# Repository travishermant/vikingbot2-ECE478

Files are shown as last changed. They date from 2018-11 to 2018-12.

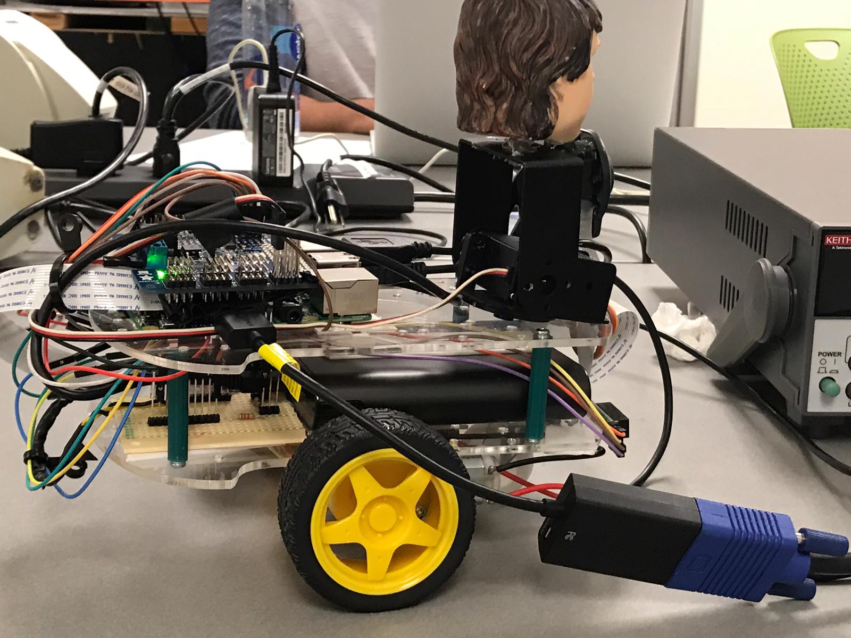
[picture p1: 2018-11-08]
Documentation/Pictures/RightView.jpeg

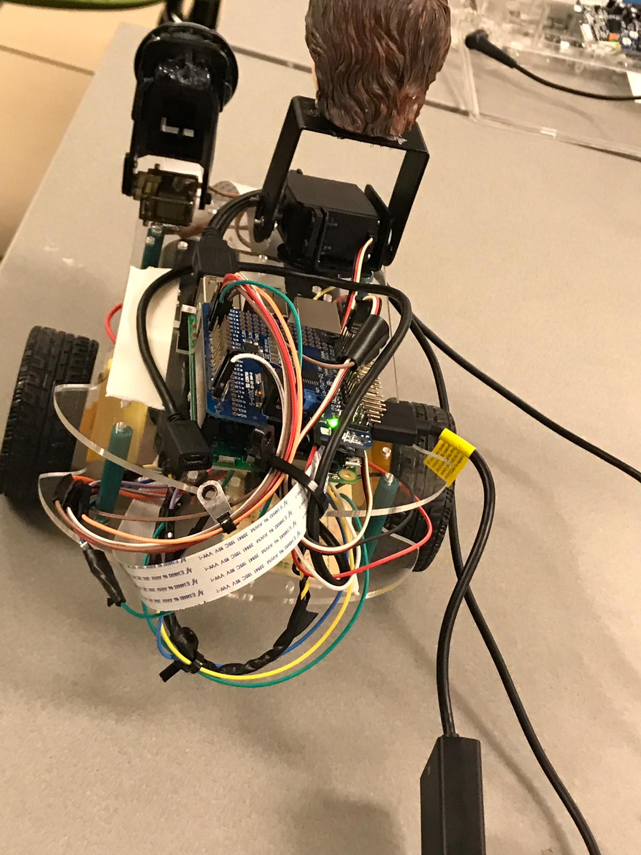
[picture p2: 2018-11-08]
Documentation/Pictures/RearView.jpeg

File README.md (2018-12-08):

# Fall 2018 - ECE478/578 - Intelligent Robotics 1
**Intelligent Robotics Lab**

**Portland State University**

# Members
- Travis Hermant (https://github.com/travishermant)
- Abdullah Barghouti (https://github.com/AbdullahBarghouti)
- Jagir Charla Laxmichand (https://github.com/gotu0000)
- Abdirahman Alasow (https://github.com/abdi-alasow)

# Project Name: Vikingbot

Vikingbot is a small motor-driven robot utilizing Python, ROS, Dialogflow, Amazon Polly, and OpenCV to perform different applications
  
# Project Goals

Facial Recognition
- Vikingbot rotates to align itself with faces it detects in front [done]

Gesture Recognition
- Vikingbot will nod its head when it sees a smile [done]

Color Tracking
- Vikingbot will rotate and follow an orange ball when it is detected [done]

IR Sensors
- Vikingbot will prevent itself from crashing by using IR sensors to detect distance from obstacles [done]

Speech to Text
- Using Dialogflow to check intents and respond with the correct actions [done]

Text to Speech
- Using Amazon Polly to convert lines of dialogue to MP3's so they can be played through speakers [done]

ROS Integration
- Previous components can now be used in conjunction with ROS rather than being used individually (No OpenCV yet) [done]

# Hardware and Software used

Software:
- OpenCV
- Python
- ROS
- Dialogflow
- Amazon Polly

Hardware: 
- Raspberry Pi 3B
- Raspberry Pi Camera
- L2938N H-Bridge
- Adafruit Servo Controller Hat
- Futaba S3003 Servo
- SDS02A Pololu IR Sensor
- 2x DC Motor Wheel Components

# Contributions
- Travis (3D Model, Servo Control, Github Organization, Dialogflow)
- Abdullah (Motor Control, Servo Control, Polly)
- Jagir (Gesture Recognition, Color Tracking, ROS)
- Abdi (Facial Recognition, Dialogflow)

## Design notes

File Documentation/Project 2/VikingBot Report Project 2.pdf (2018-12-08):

# Vikingbot

Travis Hermant
Abdullah Barghouti
Abdirahman Alasow
Jagir Laxmichand Charla

ECE 478-578 Intelligent Robotics I

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
4 Intro | 4 Overview | 4 Challenges | 7 Possible improvements | 7

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
8 Intro | 8 Overview Diagrams | 8 Coordinator | 10 Motor Motion | 10 Servo Motion | 10 Recorder | 10 Dialogflow | 10 Polly | 11 Talker | 11 Challenges | 11 Possible improvements | 11

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
2 Intro | 12 Overview | 12 Challenges | 12 Possible improvements | 13

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
4 Intro | 14 Design | 15 Challenges | 15 Possible improvements | 16

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
# Summary

The Vikingbot contains two DC motors for the wheels driven by an L293E H-Bridge making it capable of operating both wheels forward and backward in conjunction, or allows each to operate in separate directions to allow it to turn. Central processing is handled by a
Raspberry Pi 3 B with an attached Adafruit Servo Hat for PWM control of the attached servo. Coding is done with Python; an attached Pi Camera is used in conjunction with OpenCV to handle applications such as color tracking with a ball, face tracking to steer the car, and smile recognition to make the servos respond to gestures. The Vikingbot utilizes ROS to facilitate using Dialogflow to interpret commands, Amazon Polly to communicate with users, and to drive the motors and servos.

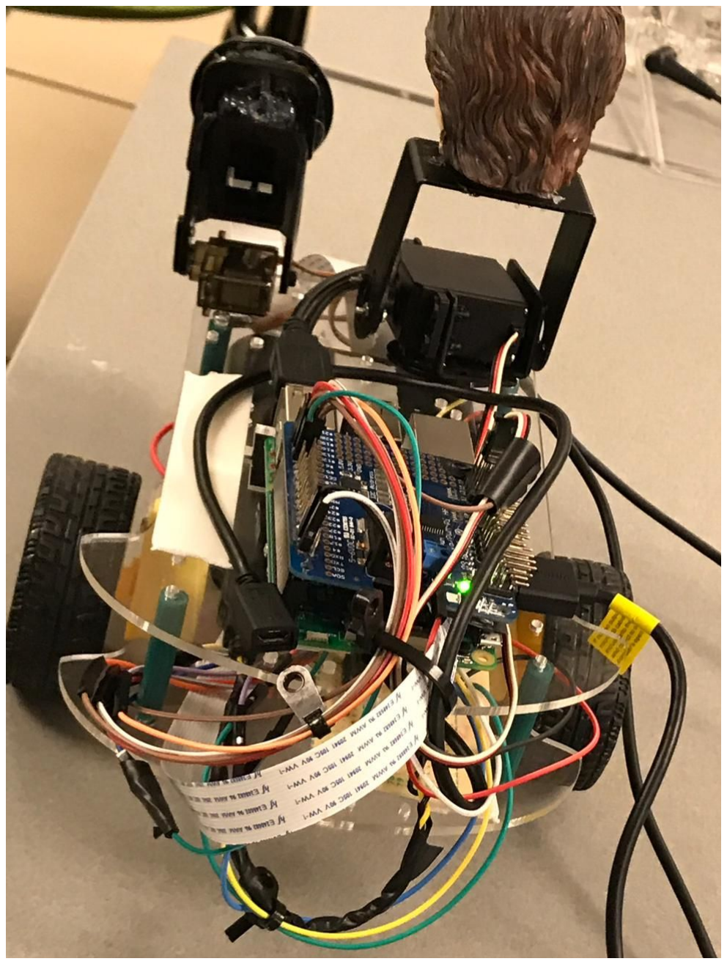
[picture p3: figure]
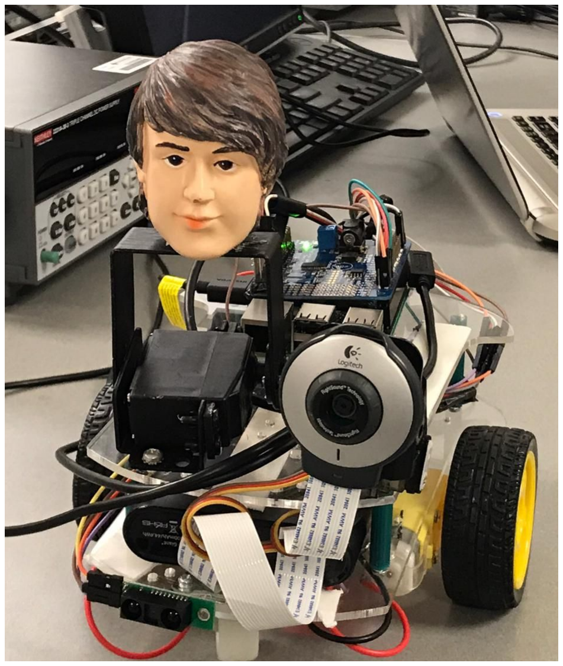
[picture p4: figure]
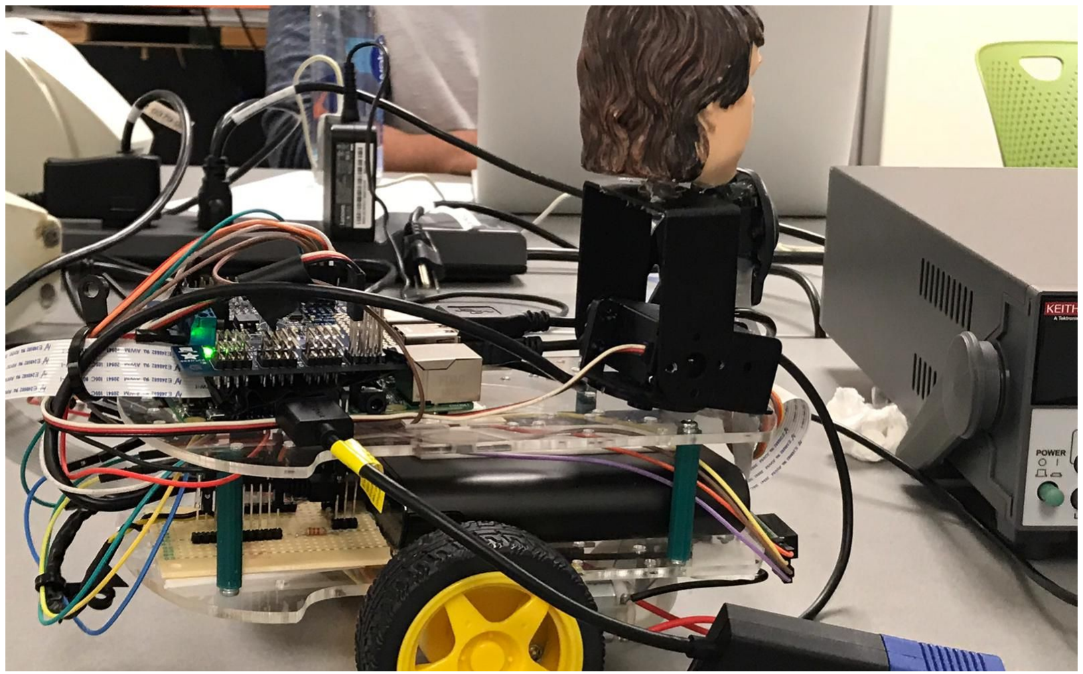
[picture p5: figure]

# Software Design

## Intro

We have 4 different independent applications for the demo:
- Ball Tracking Bot
- Face Tracking Bot
- Remote Controlled Bot
- Smile Detector Bot
Which can be broadly divided into two parts like Vision and Motion.

We have used OpenCV with python for the Vision and we have used RPI’s GPIO module for the motion.

## Overview

For Remote Controlled Bot we have made two applications talking over TCP socket. The one which actually executes the motion is TCP Server , whose task is listen to the command and execute it according to the request generated from TCP Client.

TCP Client takes data from a user in the form of letters ‘w’, ’a’, ‘s’, ‘d’ and ‘b’:
‘w’ for forward
‘a’ for left
‘s’ for stop
‘d’ for right
And ‘b’ for backward

Server also monitors IR sensor to check for the obstacle in front. It stops the motion in case of detection of obstacle.

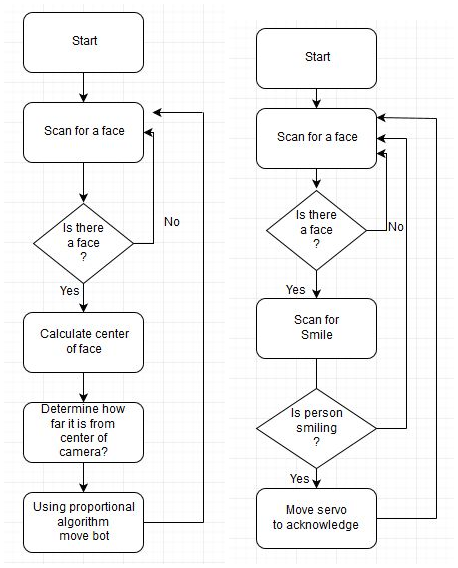
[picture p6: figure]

For smile detecting bot we have used Haar cascade classifier to detect a face in an image. After getting a face we are looking for smile in the region of interest using Haar cascade smile classifier. Depending on detection of smile we are moving the servo to make it look like a greeting gesture.
For face tracking bot we have used Haar cascade classifier to detect a face in an image. For tracking we are calculating the center of the face and determining how far it is from the center of camera. Depending on which we are rotating the bot till center of the face gets align to the center of the camera.

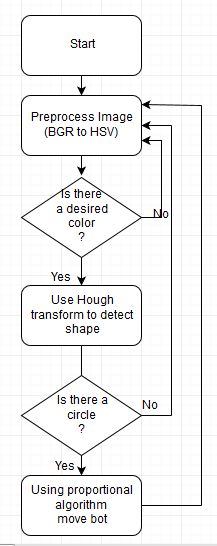
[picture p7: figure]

For ball tracking bot we have converted an image to HSV. HSV is good for color segmentation purpose. We are using hough transform to determine circles in an image. For tracking we are calculating the center of the circle and determining how far it is from the center of camera. Depending on which we are rotating the bot till center of the ball gets align to the center of the camera. After that we are comparing the area of the circle to determine how far the ball is from camera, and accordingly we are moving the bot forward if area is too small.

## Challenges

Face detection and ball detection are prone to misbehave in case of poor lighting condition. Apart from that due to various morphological operations involved in pre processing frame rate reduces.

## Possible improvements

Implementation of robust and fast methods for detection of face and ball, and integration of multiple Vision algorithms to make bot more interactive.

# ROS Design

## Intro

We have 7 different ROS nodes working in conjunction.
- Coordinator
- Motor Motion
- Servo Motion
- Recorder
- Dialogflow
- Polly
- Talker
These nodes can be used in conjunction for speech to text, text to speech, and motion commands. Currently OpenCV and Color/Facial recognition are not implemented for use in ROS.

## Overview Diagrams

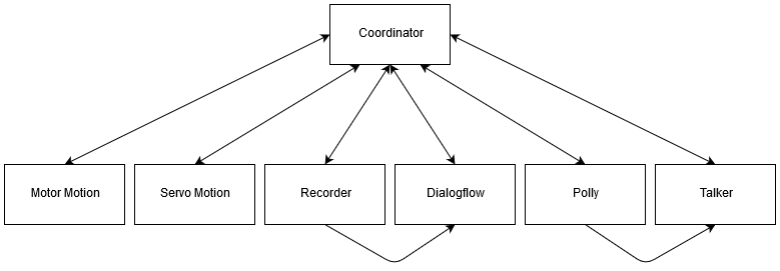
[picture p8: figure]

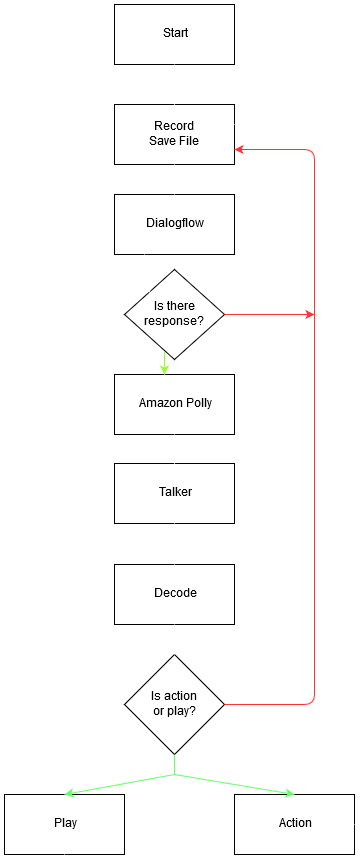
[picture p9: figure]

## Coordinator

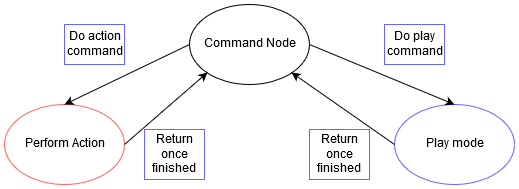
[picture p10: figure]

The coordinator node is the “brain” of the robot, deciding what should be done and sending commands to all of the nodes.

## Motor Motion

The motor motion node is a conversion of our previous driver so that they’re compatible with ROS. It is capable of moving forward, turning left and right, and going backwards.

## Servo Motion

The servo motion node is also a conversion of our previous driver for controlling the servo that the bobble head sits on. Since there is only one servo, it is only capable of one degree of freedom and can move in a 180 degree arc. Currently its usage is limited to nodding as a form of expression. In the future it will be adapted to accompany additional servos for the arms.

## Recorder

The recorder node is where the microphone will catch audio in 5 second loops and convert them into WAV files. The audio isn’t parsed here though, and will instead need to be sent out to the Dialogflow node

## Dialogflow

The Dialogflow node will send the WAV files it receives from the Recorder node to the Google API servers, where it will be analyzed to return the intent so that the proper actions can be taken. Actions Dialogflow can detect are: entering ‘theater’ mode, turning ‘left’, turning ‘right’, going ‘forward’, and going ‘backward’.

## Polly

The Amazon Polly node is used to convert text to speech. Lines of the play are sent in a string to the AWS servers, where the string is then converted to an MP3 files. Polly is configured to speak in a Male British accent, to coincide with our play script following Alan Turing.

## Talker

The Talker node is used to drive the speakers with MP3s that are generated by Amazon Polly. The talker node also takes in the spoken speech and decodes it to identify what mode/ action the robot should enter.

## Challenges

ROS is difficult to set up and having the capability of running nodes on different computers is nice, but also complicated. It is difficult to use Amazon Polly and Dialogflow because they both require internet and establishing a connection to the internet in conjunction with multiple robots/computers is also a complicated task.

## Possible improvements

Currently, the Vikingbot is running solo and does not have any communication set up between it and another robot. A method of communication between the raspberry pi, a parent computer, and another robot is vital for further development.
Pulse Width Modulation should be added to the motor for the wheels, so that we can vary the speed at which the robot moves around. PWM would greatly increase our ability to emote and give greater control over what we want it to do.
We still have our temporary design in use due to complications with the 3D printers, so we’re limited in what we can do to increase functionality through hardware. Eventually when we have the new design, we can add new components such as an extra battery to separate the power draw from the servos, which would allow us to add more servos.

# Hardware Design

## Intro

During our initial stages of designing and assembling the robot’s hardware, we figured it would be useful to list the parts we will make use of in our robot design. From our group discussions, we concluded that we would incorporate the DC motors that came with the robot base, raspberry pi 3b, raspberry pi hat, servo motors, portable battery pack, and an IR infrared obstacle avoidance sensor. We also used a voltage divider to step down the voltage from the power supply from 5v to 3.3v so that it can be wired to the raspberry pi pins safely.
We used the raspberry pi hat as a safety precaution to ensure that the servo motors we attach to the main board don’t draw too much power and damage our raspberry pi. The Hardware Attached on Top (HAT) also allows us to connect up to 16 servo motors and has a 5-volt input to ease the power draw on our main board.

## Overview

To use the raspberry pi pins, we had to use a voltage divider with a 1k ohm and 2k ohm resistors so that the power input on the pins is dropped from 5v to the rated 3.3 volts. To connect the servo motors we used the hardware attached on the top chip to protect the main board from any access power draw. This chip allows for protection and adds the capability to add up to 16 servos and another power input to suffice the needed current and voltage to power all the added components connected to it.
Our current design allows for the servo motor with the bobblehead to move in a single direction (upwards and downwards), our design, however, allows for up to 2 motors (right and left movement as well) but because of the power limitations, we had to omit the second servo.

## Challenges

Because of our limited power supply, we had issues connecting more than one servo to our robot. Connecting the servos, raspberry pi, DC motors, and the camera drew just enough power that adding another servo motor caused the raspberry pi to shut off.
Setting up google dialog flow was tedious at first but the video uploaded by Melih Erdogan made things more manageable.
Due to the limited bandwidth, the connection between the raspberry pi and host computer was lagging and causing lots of delays. To overcome this challenge, we were forced to use a wired connection

## Possible improvements

The power supply that we used was not powerful enough to support all the components we had connected to it. A future improvement would be to find a better alternative to supply the needed power to all our components while still keeping the robot relatively light and mobile.

# Enclosure Design

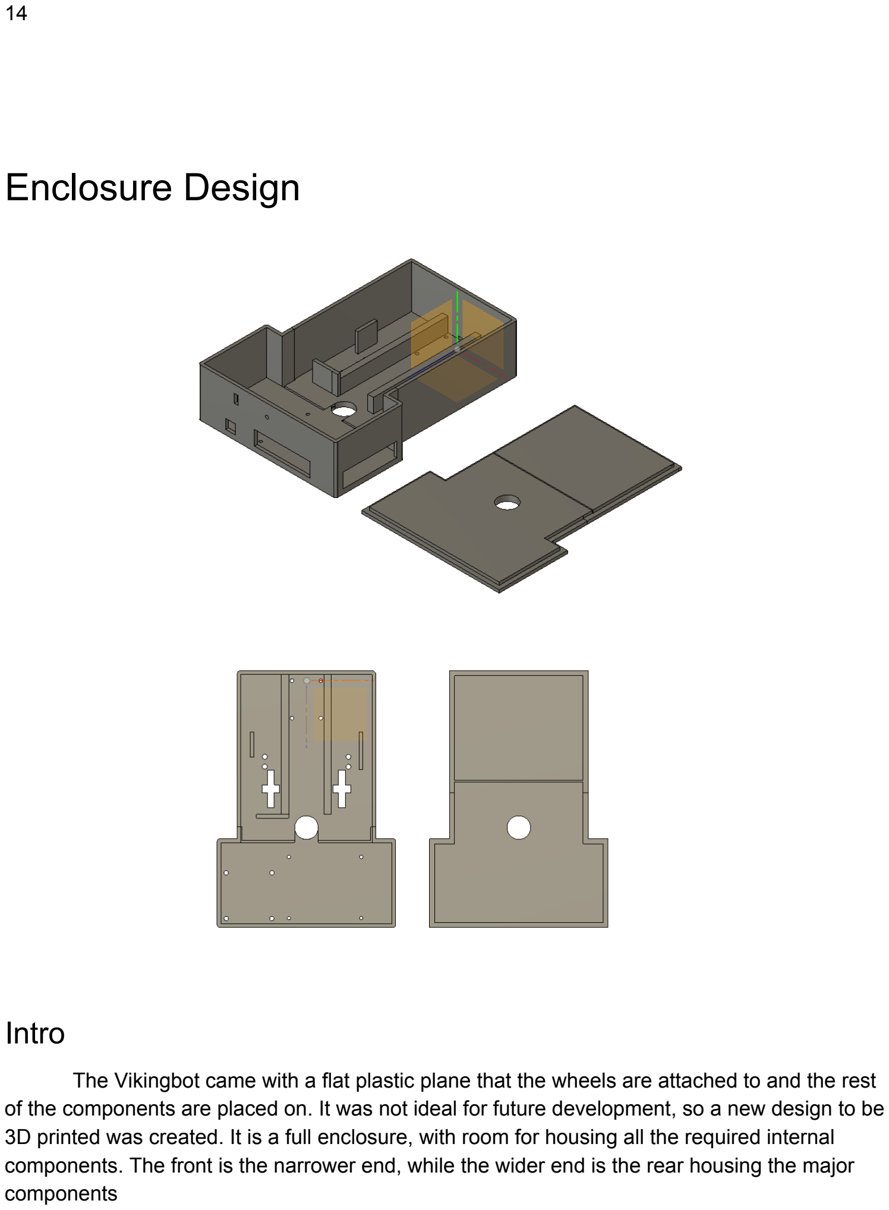
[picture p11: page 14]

## Intro

The Vikingbot came with a flat plastic plane that the wheels are attached to and the rest of the components are placed on. It was not ideal for future development, so a new design to be 3D printed was created. It is a full enclosure, with room for housing all the required internal components. The front is the narrower end, while the wider end is the rear housing the major components

## Design

The enclosure is roughly 50mm tall, allowing ample room for components to rest inside without cramping wires or worrying about heating issues. The battery is easily the largest component in the Vikingbot, and is placed on small stands at the front of the enclosure to keep the center of gravity on the wheels and help any potential stability issues. The input and output of the battery will be facing inwards, which then makes charging difficult. To circumvent that issue we connected a micro USB extension cable and added a cutout in the back of the model for charging purposes. In the future there will be encoder wheels located in the cross shaped cutouts; the battery was placed on stands a few millimeters more than the encoder wheels should require.
The Raspberry Pi will be located in the bottom right corner of the enclosure and has four corresponding screw holes for security, with cutouts in the enclosure corresponding to the Pi’s USB and HDMI ports so they can be accessed from the outside. Since the Pi has the Servo Hat installed on it, it will be considerably taller than without, but the large amount of clearance shouldn’t make that an issue.
The H-Bridge will be located in the bottom left corner of the enclosure, with its own corresponding four screw holes. There is a small amount of room in the rear compartment for relevant connections or solder boards to rest, although there is no specific security points for them.
The large hole in the center of the base and lid provides a place for wires to safely route through. The hole for the base will have the H-Bridge wires to connect to the bottom motors. The hole in the lid will have wires for the camera and servo to run through. There is a small, rectangular slit located in the front and back for the IR sensors to have safe places to run their connections through. The two sets of two holes directly next to the cross shaped cutouts are for the motor driven wheel screws, the four holes near the front are for the supporting wheel to attach to for balance

## Challenges

Due to the length of the enclosure (roughly 205mm) it would not be able to print with our current 3D printers. To circumvent this, we cut the base and lid into their own separate halves and have decided to either glue or drill through and screw together when finished printing. This raises concerns for stability issues, but with sufficient enough fastening should not pose an issue. One benefit however is that it adds slightly more modularity, as now modifications in the 3D model design would only have to be done in sections, rather than having to print the entire enclosure again.
There were unforeseen issues with 3D printers on campus, and we weren’t able to have the models printed in time for the demo and end of project 1. As a temporary solution we used the base of the other Vikingbot and added some spacers so some components could be sat on top. It is functional enough in its current state, but somewhat difficult to work with and not too pleasant to look at.

## Possible improvements

As it stands now, the lid is free of any mounting holes aside from the hole to route wires through. Once the location of servos and cameras is finalized they can be added to the 3D design. The mounting locations on the front and back for the IR sensors will most likely fail when it comes to 3D printing, so their locations may need to be modified or otherwise changed so that drilling a hole isn’t necessary.
Depending on any stability issues due to the base and lid being split in half, the 3D design may need to be changed to better allocate support and have added dedicated holes to screw both pieces together.
While mostly functional in application, the final design is a little on the boring side. The simple ‘T’ shape can be changed into interesting ways. We may also want to have a custom 3D printed head/body for the lid to fully integrate each aspect of the Vikingbot.

# Conclusion

This project incorporated all the movement and functionality that we had in the first project. For this project we used ROS to publish and subscribe to nodes, Google Dialogflow to create text from speech, and Amazon Polly to create speech from text. By the end of the project, the VikingBot supported motion, computer vision, speech to text, and text to speech.

# Resources

Github:
https://github.com/travishermant/vikingbot2-ECE478
Youtube:
https://www.youtube.com/channel/UClnZui7ccUFAsCJwCExTw2A

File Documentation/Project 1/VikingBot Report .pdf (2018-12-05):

# Vikingbot

Travis Hermant
Abdullah Barghouti
Abdirahman Alasow
Jagir Laxmichand Charla

ECE 478-578 Intelligent Robotics I

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
alle

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
sible im

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
8 Intro | 8 Design | 8 Challenges | 9 Possible improvements | 9

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
0 Intro | 10 Design | 11 Challenges | 11 Possible improvements | 12

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
# Summary

The Vikingbot contains two DC motors for the wheels driven by an L293E H-Bridge making it capable of operating both wheels forward and backward in conjunction, or allows each to operate in separate directions to allow it to turn. Central processing is handled by a
Raspberry Pi 3 B with an attached Adafruit Servo Hat for PWM control of the attached servos. Coding is done with Python; an attached Pi Camera is used in conjunction with OpenCV to handle applications such as color tracking with a ball, face tracking to steer the car, and smile recognition to make the servos respond to gestures.

# Software

# Intro

We have 4 different independent applications for the demo.
- Ball Tracking Bot
- Face Tracking Bot
- Remote Controlled Bot
- Smile Detector Bot
Which can be broadly divided into two parts like Vision and Motion.

We have used OpenCV with python for the Vision and we have used RPI’s GPIO module for the motion.

## Design

For Remote Controlled Bot we have made two applications talking over TCP socket. The one which actually executes the motion is TCP Server , whose task is listen to the command and execute it according to the request generated from TCP Client.

TCP Client takes data from a user in the form of letters ‘w’, ’a’, ‘s’, ‘d’ and ‘b’

‘w’ for forward
‘a’ for left
‘s’ for stop
‘d’ for right
And ‘b’ for backward

Server also monitors IR sensor to check for the obstacle in front. It stops the motion in case of detection of obstacle.

For face tracking bot we have used Haar cascade classifier to detect a face in an image. For tracking we are calculating the center of the face and determining how far it is from the center of camera. Depending on which we are rotating the bot till center of the face gets align to the center of the camera.

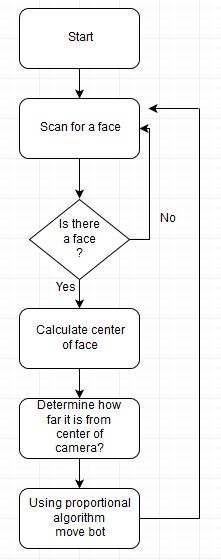
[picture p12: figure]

For smile detecting bot we have used Haar cascade classifier to detect a face in an image. After getting a face we are looking for smile in the region of interest using Haar cascade smile classifier. Depending on detection of smile we are moving the servo to make it look like a greeting gesture.

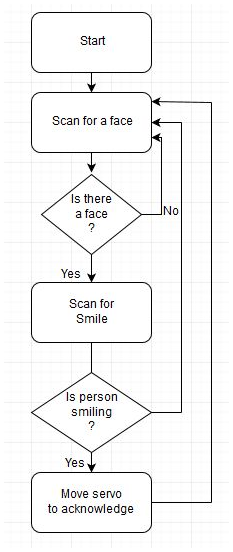
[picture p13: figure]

For ball tracking bot we have converted an image to HSV. HSV is good for color segmentation purpose. We are using hough transform to determine circles in an image. For tracking we are calculating the center of the circle and determining how far it is from the center of camera. Depending on which we are rotating the bot till center of the ball gets align to the center of the camera. After that we are comparing the area of the circle to determine how far the ball is from camera, and accordingly we are moving the bot forward if area is too small.


## Challenges

Face detection and ball detection are prone to misbehave in case of poor lighting condition. Apart from that due to various morphological operations involved in pre processing frame rate reduces.

## Possible improvements

Implementation of robust and fast methods for detection of face and ball. And Integration of multiple Vision algorithms to make bot more interactive.

# Hardware

## Intro

During our initial stages of designing and assembling the robot’s hardware, we figured it would be useful to list the parts we will make use of in our robot design. From our group discussions, we concluded that we would incorporate the DC motors that came with the robot base, raspberry pi 3b, raspberry pi hat, servo motors, portable battery pack, and an IR infrared obstacle avoidance sensor. We also used a voltage divider to step down the voltage from the power supply from 5v to 3.3v so that it can be wired to the raspberry pi pins safely.
We used the raspberry pi hat as a safety precaution to ensure that the servo motors we attach to the main board don’t draw too much power and damage our raspberry pi. The Hardware Attached on Top (HAT) also allows us to connect up to 16 servo motors and has a 5-volt input to ease the power draw on our

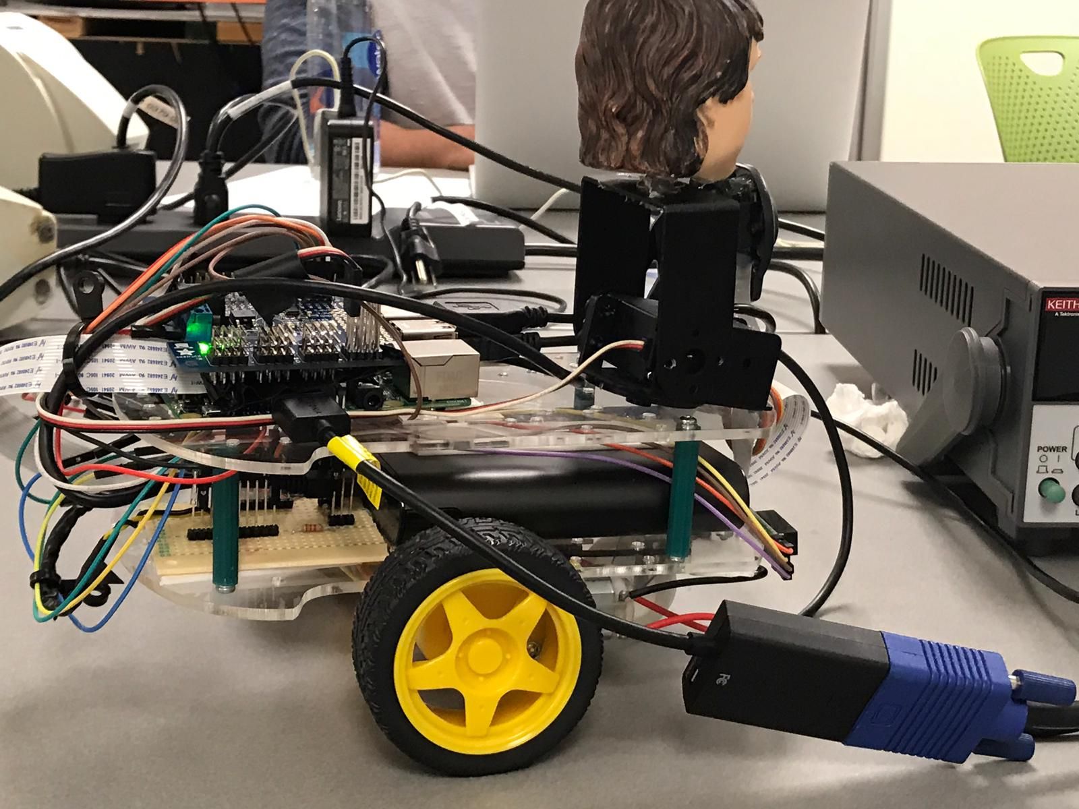
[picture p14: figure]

main board.

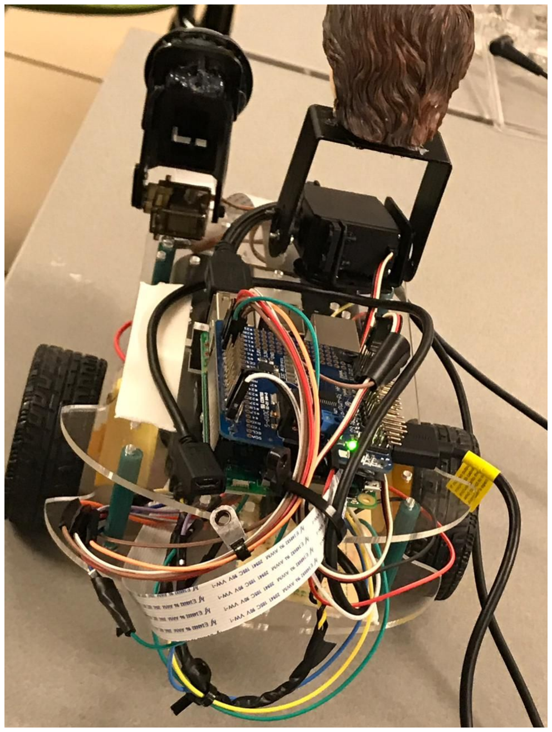
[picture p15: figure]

## Design

To use the raspberry pi pins, we had to use a voltage divider with a 1k ohm and 2k ohm resistors so that the power input on the pins is dropped from 5v to the rated 3.3 volts. To connect the servo motors we used the hardware attached on the top chip to protect the main board from any access power draw. This chip allows for protection and adds the capability to add up to 16 servos and another power input to suffice the needed current and voltage to power all the added components connected to it. Our current design allows for the servo motor with the bobblehead to move in a single direction (upwards and downwards), our design, however, allows for up to 2 motors (right and left movement as well) but because of the power limitations, we had to omit the second servo.

## Challenges

Because of our limited power supply, we had issues connecting more than one servo to our robot. Connecting the servos, raspberry pi, DC motors, and the camera drew just enough power that adding another servo motor caused the raspberry pi to shut off.

## Possible improvements

The power supply that we used was not powerful enough to support all the components we had connected to it. A future improvement would be to find a better alternative to supply the needed power to all our components while still keeping the robot relatively light and mobile.

# Enclosure Design

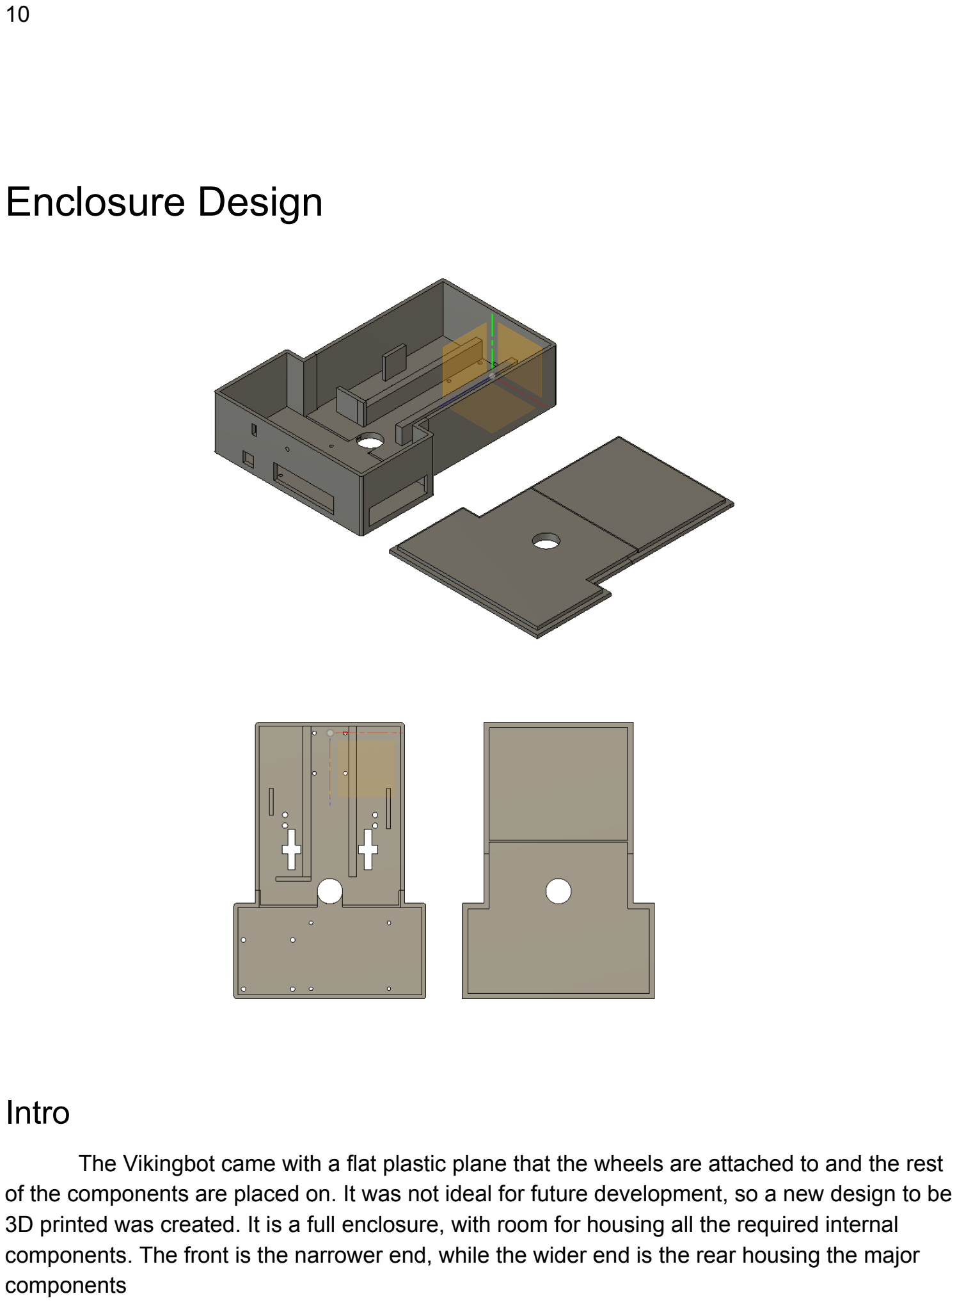
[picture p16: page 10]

## Intro

The Vikingbot came with a flat plastic plane that the wheels are attached to and the rest of the components are placed on. It was not ideal for future development, so a new design to be 3D printed was created. It is a full enclosure, with room for housing all the required internal components. The front is the narrower end, while the wider end is the rear housing the major components

## Design

The enclosure is roughly 50mm tall, allowing ample room for components to rest inside without cramping wires or worrying about heating issues. The battery is easily the largest component in the Vikingbot, and is placed on small stands at the front of the enclosure to keep the center of gravity on the wheels and help any potential stability issues. The input and output of the battery will be facing inwards, which then makes charging difficult. To circumvent that issue we connected a micro USB extension cable and added a cutout in the back of the model for charging purposes. In the future there will be encoder wheels located in the cross shaped cutouts; the battery was placed on stands a few millimeters more than the encoder wheels should require.
The Raspberry Pi will be located in the bottom right corner of the enclosure and has four corresponding screw holes for security, with cutouts in the enclosure corresponding to the Pi’s USB and HDMI ports so they can be accessed from the outside. Since the Pi has the Servo Hat installed on it, it will be considerably taller than without, but the large amount of clearance shouldn’t make that an issue.
The H-Bridge will be located in the bottom left corner of the enclosure, with its own corresponding four screw holes. There is a small amount of room in the rear compartment for relevant connections or solder boards to rest, although there is no specific security points for them.
The large hole in the center of the base and lid provides a place for wires to safely route through. The hole for the base will have the H-Bridge wires to connect to the bottom motors. The hole in the lid will have wires for the camera and servo to run through. There is a small, rectangular slit located in the front and back for the IR sensors to have safe places to run their connections through. The two sets of two holes directly next to the cross shaped cutouts are for the motor driven wheel screws, the four holes near the front are for the supporting wheel to attach to for balance

## Challenges

Due to the length of the enclosure (roughly 205mm) it would not be able to print with our current 3D printers. To circumvent this, we cut the base and lid into their own separate halves and have decided to either glue or drill through and screw together when finished printing. This raises concerns for stability issues, but with sufficient enough fastening should not pose an issue. One benefit however is that it adds slightly more modularity, as now modifications in the 3D model design would only have to be done in sections, rather than having to print the entire enclosure again.
There were unforeseen issues with 3D printers on campus, and we weren’t able to have the models printed in time for the demo and end of project 1. As a temporary solution we used the base of the other Vikingbot and added some spacers so some components could be sat on top. It is functional enough in its current state, but somewhat difficult to work with and not too pleasant to look at.

## Possible improvements

As it stands now, the lid is free of any mounting holes aside from the hole to route wires through. Once the location of servos and cameras is finalized they can be added to the 3D design. The mounting locations on the front and back for the IR sensors will most likely fail when it comes to 3D printing, so their locations may need to be modified or otherwise changed so that drilling a hole isn’t necessary.
Depending on any stability issues due to the base and lid being split in half, the 3D design may need to be changed to better allocate support and have added dedicated holes to screw both pieces together.
While mostly functional in application, the final design is a little on the boring side. The simple ‘T’ shape can be changed into interesting ways. We may also want to have a custom 3D printed head/body for the lid to fully integrate each aspect of the Vikingbot.

# Conclusion

All in all this project was a great learning experience. We got to explore 3D printing, openCV, and controlling the motors/ servos. We created a 3D design to house all the components of the robot and ensure that they remain secure during transportation and operation. Using OpenCV we implemented facial recognition and object tracking functionality to achieve ball tracking, face tracking, smile detection, and remote controlled access to both motors. As a safety measure, we used an IR sensor for obstacle avoidance while moving.
Throughout the time we spent on this project, we found many improvements that we would have added if we had more time. Some of these improvements include: adding a speaker for speech
synthesis, add another battery to power any added
components, and integrate all the OpenCV

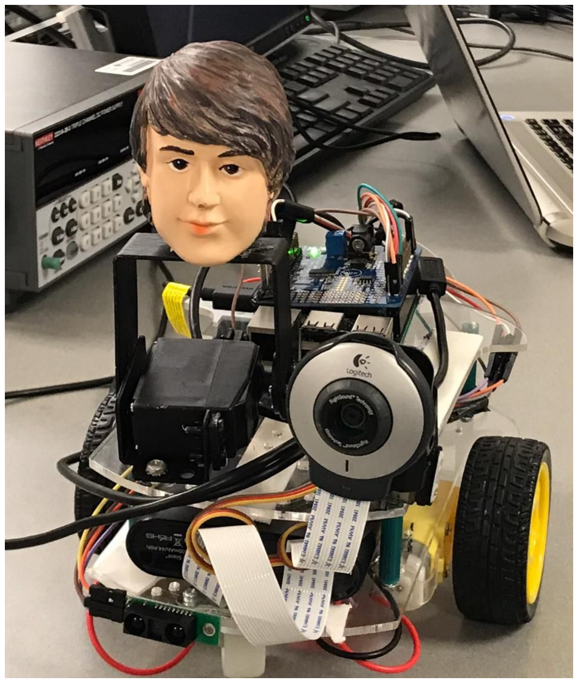
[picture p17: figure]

algorithms in a single application so that its organized in a more efficient way

# Resources

Github:
https://github.com/travishermant/vikingbot2-ECE478
Youtube:
https://www.youtube.com/channel/UClnZui7ccUFAsCJwCExTw2A

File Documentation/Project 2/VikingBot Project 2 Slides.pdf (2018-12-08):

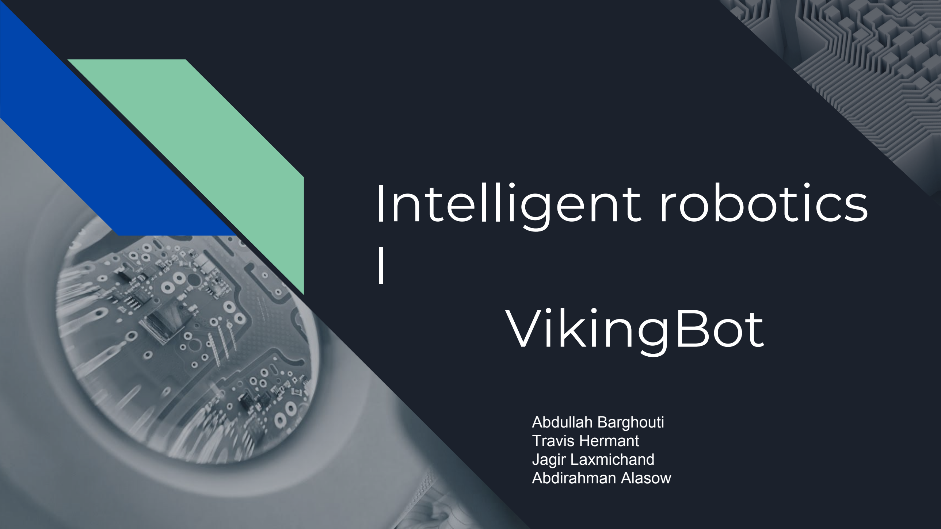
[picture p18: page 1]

# Intelligent robotics

I

# VikingBot

Abdullah Barghouti
Travis Hermant
Jagir Laxmichand
Abdirahman Alasow

# Overview

Components:
- 2 DC motors
- Raspberry pi 3B
- Raspberry pi camera
- Servo motors
- IR sensor

Robot Features (using ROS):
- Movement (forward, backwards, right, left)
- Bobble head (up and down)
- Speech to text, text to speech

# Software

Tools used:

ROS with:

- Python
- OpenCV
- NumPy
- dialog flow
- Amazon Polly

Issues:

- Finding the right libraries
- Difficulties connecting wirelessly
- Setting up dialog flow
- dialog flow to comprehend speech in a noisy environment

# ROS

- The Robot Operating System (ROS)
- Creates an operating system for tools and libraries to communicate seamlessly
- Aids in creating robust software

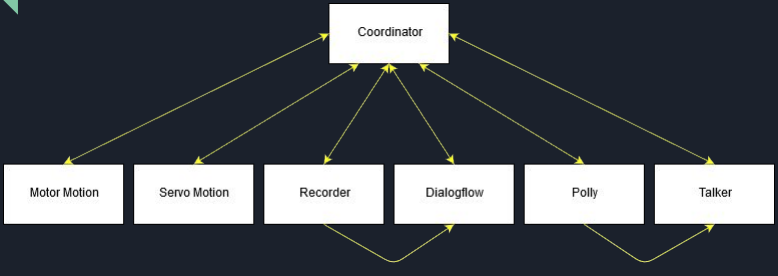
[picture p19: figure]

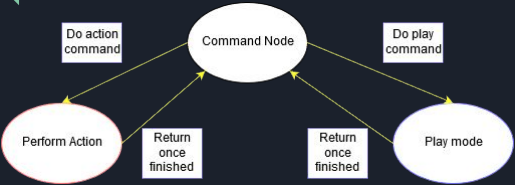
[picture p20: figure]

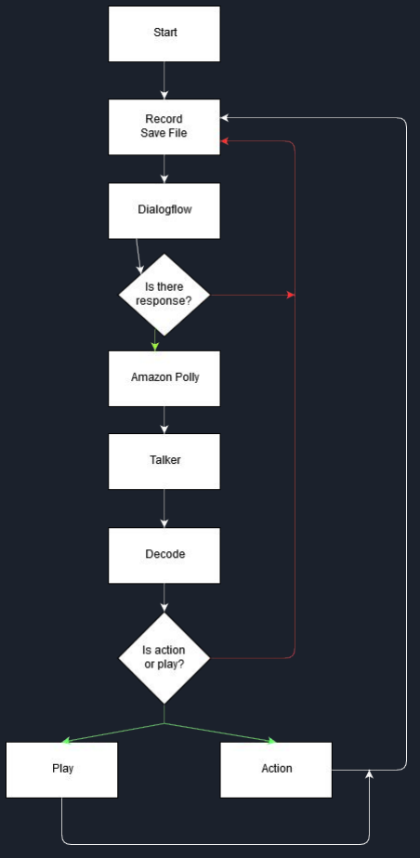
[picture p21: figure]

# DialogFlow

Parses speech and looks for intents in .wav files it is sent

“Intents” are used to find keywords and link them to their appropriate reaction

# Amazon Polly

- Use Amazon Polly to convert text to speech
- Allows for multiple languages and accents
- Provides lifelike speech
- Very versatile

# Motor Movement

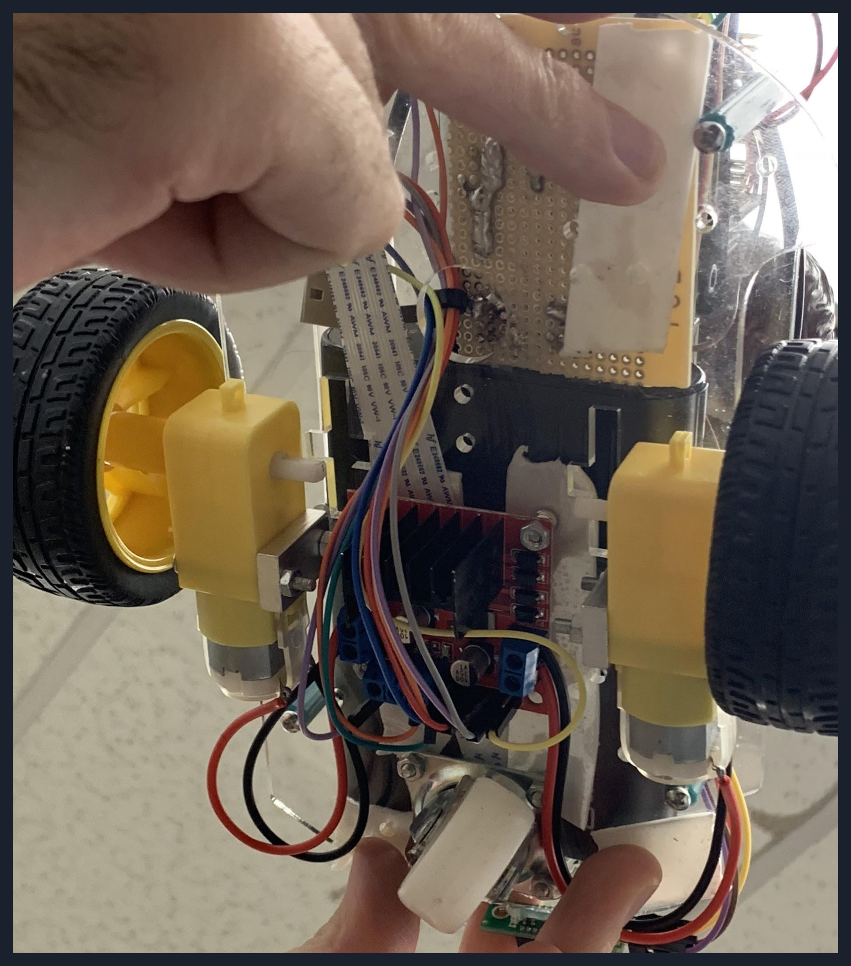
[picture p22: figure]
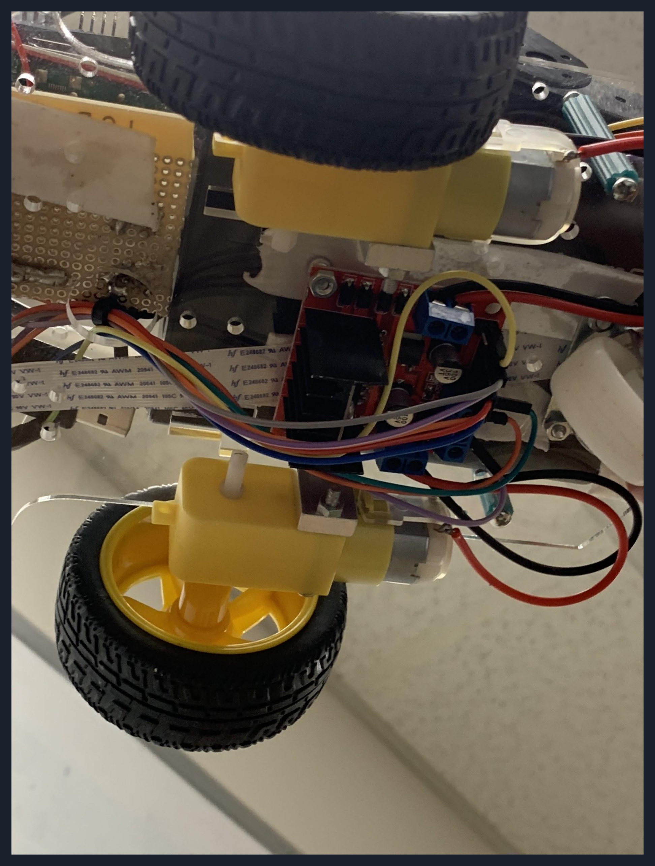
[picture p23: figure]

- Create a driver that is referenced by other modules to move the robot
- L293E H-bridge
- In the future, duty cycles to be added for different speeds

# Servo Movement

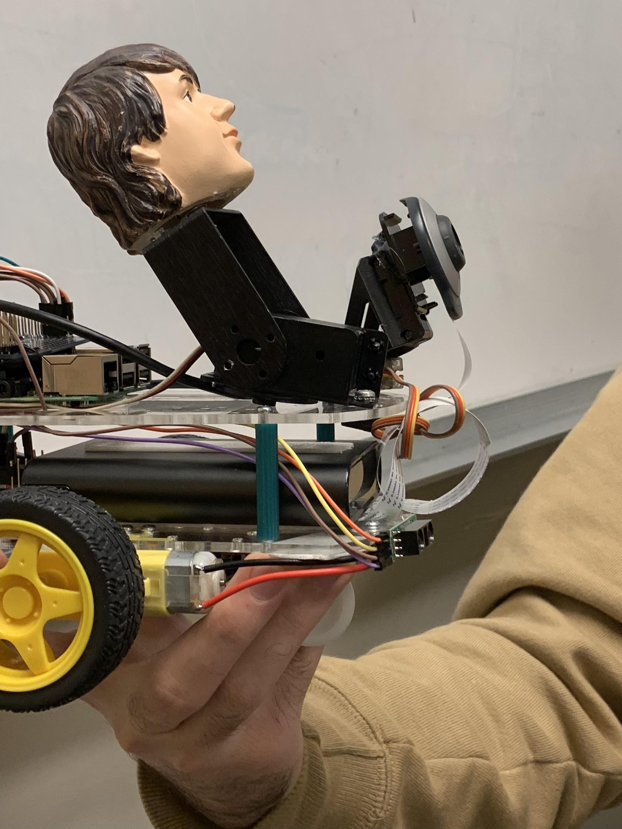
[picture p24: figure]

Due to singular servo, it is limited to one axis of movement

Since the primary function of the robot is as a car, the servo acts as a mechanism for gestures and is connected to the head

# Improvements

- Connect Pi to internet while using Ros so dialogflow and polly work correctly
- Or have this done on computer
- Communication with second robot
- When case is printed, more mechanics can be added such as additional servos

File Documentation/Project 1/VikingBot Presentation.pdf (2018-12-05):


# Intelligent robotics

I

# VikingBot

Abdullah Barghouti
Travis Hermant
Jagir Laxmichand
Abdirahman Alasow

# Overview

Components:
- 2 DC motors
- Raspberry pi 3B
- Raspberry pi camera
- Servo motors
- IR sensor

Robot Features:
- Movement (forward, backwards, right, left)
- Bobble head (up and down)
- Image and gesture detection
- Obstacle avoidance

# 3D Design

Achievements:

- Design that houses all the components
- Light and compact design
- Secure all components in place during operation and transportation

Issues:

- Split into 4 pieces for printing
- Will require some drilling for sensors on front and back that would fail during printing

# 3D Design pictures and schematics

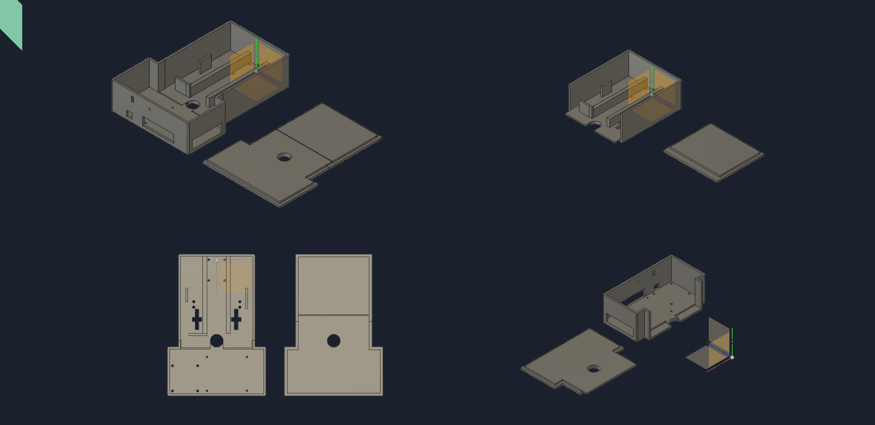
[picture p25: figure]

# Hardware

Achievements:

- Car is very fast
- Servos are strong and with full rotation
- Pi Camera is integrated with OpenCV
- H-Bridge controls motor movement

Issues:

- Car is sometimes too fast
- Cannot power two servos
- Raspberry Pi may require own PSU

# Hardware Pictures and connections

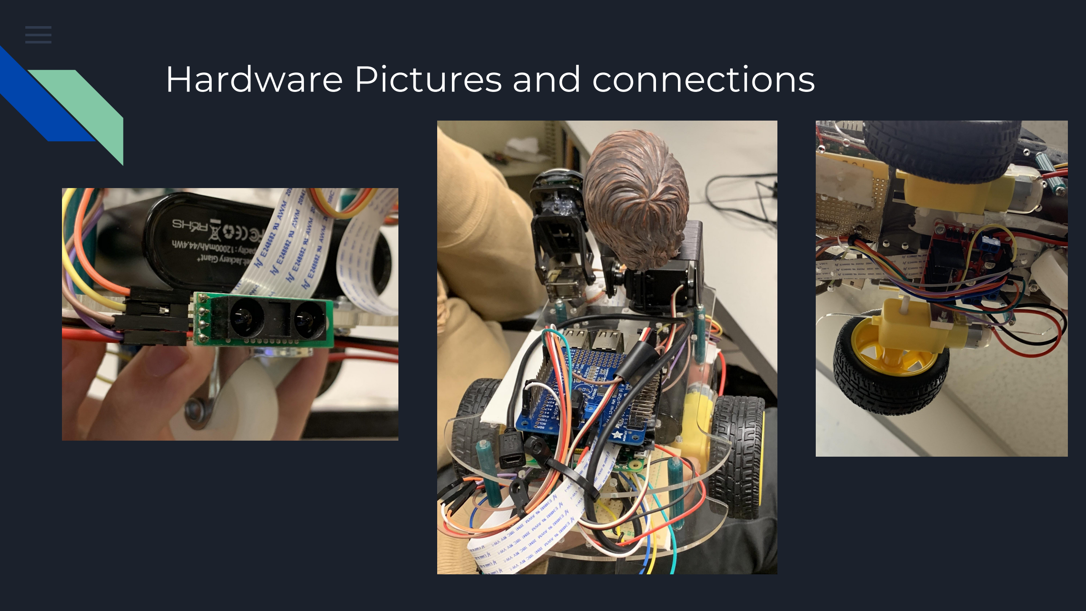
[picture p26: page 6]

# Software

Tools used:

- Python
- OpenCV
- NumPy

Issues:

- Finding the right libraries
- Difficulties connecting wirelessly

# Motor Movement


- Create a driver that is referenced by other modules to move the robot
- L293E H-bridge


# Servo Movement


Due to singular servo, it is limited to one axis of movement

Since the primary function of the robot is as a car, the servo acts as a mechanism for gestures and is connected to the head

There is a secondary servo attached to the camera, it is unplugged due to power
constraints, but if that is solved it can

# Facial tracking


if (220 <= (x + (w/2)) <= 420): RobotSTOP()

elif ((x + (w/2)) < 220): RobotLEFT()

elif((x + (w/2)) > 420): RobotRIGHT()

# Ball Detection and Tracking

- Segmentation based on colour
- Transforming image into HSV (i.e. Hue Saturation View)
- Masking an Image based on threshold value of color
- Hough transform and contour detection to get the region of interest
- Proportional algorithm to track a ball

# Smile Detection

- Use of common haar like features
- Preprocessing for Haar cascade classifier
- Haar cascade as a kernel to detect a face
- Use Haar cascade smile kernel to identify the smile
- Movement of servo based on smile detection

# Overall possible improvements

- Case needs to be 3D printed and assembled
- Possible 3D printed head
- Speaker for sound
- More robust implementation of each component
- May need small battery for pi itself, so if servos/motors draw too much power it won’t shut down
- Might need to implement duty cycles for motor driver so it can operate at different speeds
- Integration of various OpenCV algorithms in single application

# Conclusion

- All in all the project was a great learning experience. We got to explore 3D printing, OpenCV, and controlling the motors/ servos.
- Using openCV we implemented facial recognition and object tracking functionality
- The IR sensor allows to avoid obstacles while tracking an object/ face

# Videos

OpenCV (https://www.youtube.com/watch?v=mptnHqGMbd4)

Servo (https://www.youtube.com/watch?v=SofuN0Qs-xc)

VikingBot object detection (https://www.youtube.com/watch?v=KhXjvCAiKs4)

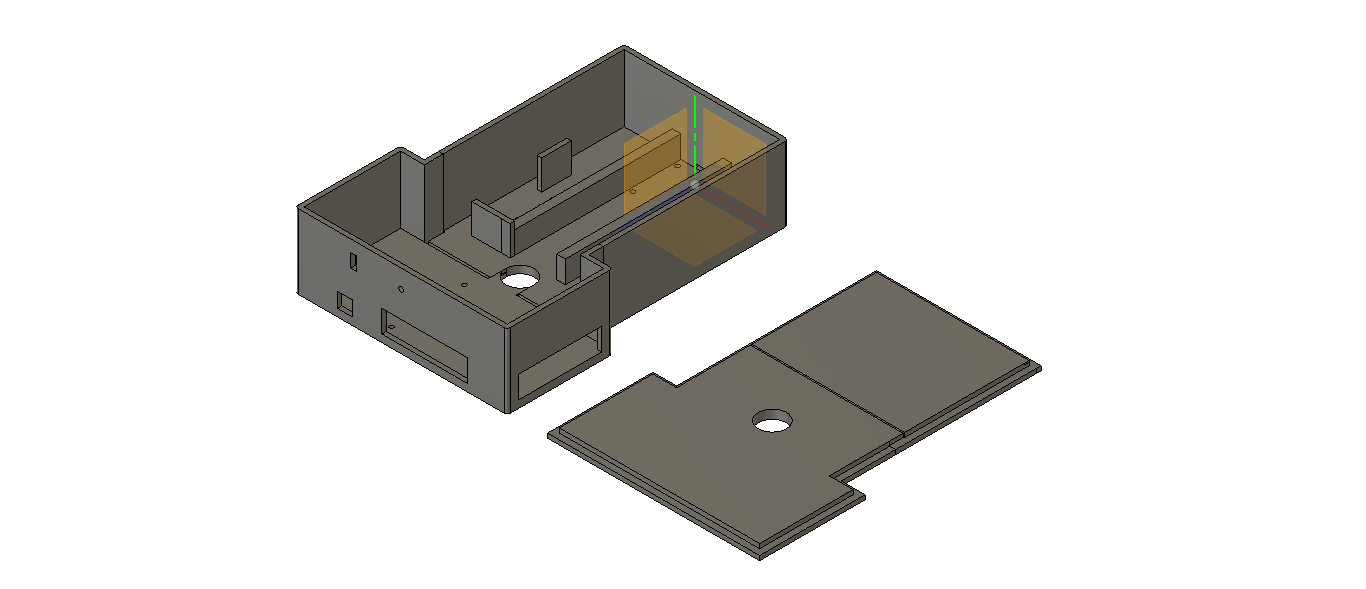
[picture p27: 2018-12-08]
Documentation/Pictures/OverviewPic.png

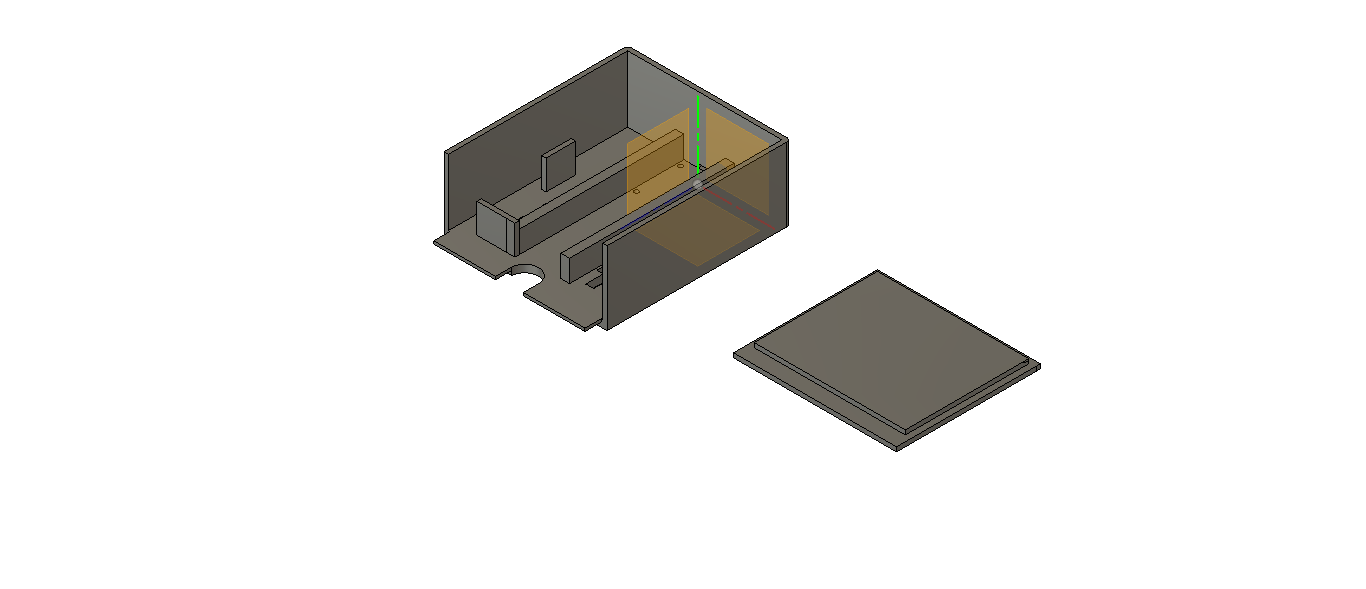
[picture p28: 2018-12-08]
Documentation/Pictures/FirstHalf.png

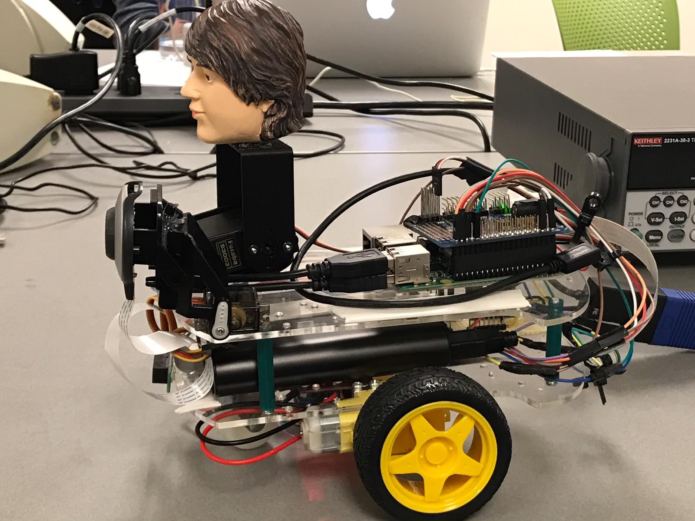
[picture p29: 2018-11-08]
Documentation/Pictures/LeftView.jpeg

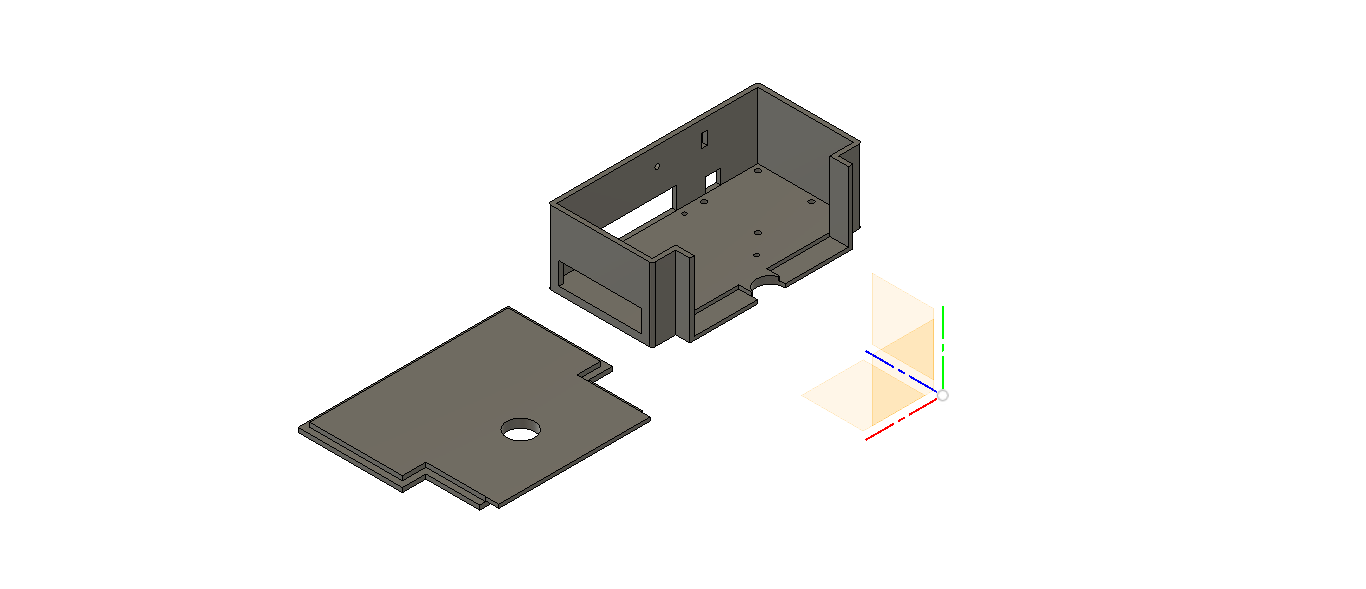
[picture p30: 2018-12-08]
Documentation/Pictures/SecondHalf.png

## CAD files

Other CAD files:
Documentation/Case Design/Vikingbot v10.f3d
Documentation/Case Design/Vikingbot v12.f3d
Documentation/Case Design/Vikingbot v4.f3d

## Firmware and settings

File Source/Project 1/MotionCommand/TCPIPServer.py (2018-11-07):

import socket
import sys
import time


import RPi.GPIO as GPIO


#switches on the H-bridge
L293E_IN1 = 21  
L293E_IN2 = 26
L293E_IN3 = 16
L293E_IN4 = 20
EN_1 = 13
EN_2 = 12
IR_PIN = 19

def RobotInit():
    GPIO.setmode(GPIO.BCM)
    #initializing GPIO pins to low outputs 
    GPIO.setup(L293E_IN1,GPIO.OUT,initial=GPIO.LOW)
    GPIO.setup(L293E_IN2,GPIO.OUT,initial=GPIO.LOW)
    GPIO.setup(L293E_IN3,GPIO.OUT,initial=GPIO.LOW)
    GPIO.setup(L293E_IN4,GPIO.OUT,initial=GPIO.LOW)
    GPIO.setup(EN_1,GPIO.OUT,initial=GPIO.HIGH)
    GPIO.setup(EN_2,GPIO.OUT,initial=GPIO.HIGH)

#movement logic
def RobotFWD():
	GPIO.output(L293E_IN1,False)
	GPIO.output(L293E_IN2,True)
	GPIO.output(L293E_IN3,False)
	GPIO.output(L293E_IN4,True)
    
def RobotBACK():
	GPIO.output(L293E_IN1,True)
	GPIO.output(L293E_IN2,False)
	GPIO.output(L293E_IN3,True)
	GPIO.output(L293E_IN4,False)

def RobotLEFT():
	GPIO.output(L293E_IN1,False)
	GPIO.output(L293E_IN2,True)
	GPIO.output(L293E_IN3,True)
	GPIO.output(L293E_IN4,False)

def RobotRIGHT():
	GPIO.output(L293E_IN1,True)
	GPIO.output(L293E_IN2,False)
	GPIO.output(L293E_IN3,False)
	GPIO.output(L293E_IN4,True)
	
def RobotSTOP():
	GPIO.output(L293E_IN1,False)
	GPIO.output(L293E_IN2,False)
	GPIO.output(L293E_IN3,False)
	GPIO.output(L293E_IN4,False)

def RobotDeInit():
    GPIO.cleanup()


RobotInit()
GPIO.setup(IR_PIN,GPIO.IN,pull_up_down=GPIO.PUD_UP)

sock = socket.socket(socket.AF_INET, socket.SOCK_STREAM)
sock.setsockopt(socket.SOL_SOCKET, socket.SO_REUSEADDR, 1)
sock.settimeout(0.0025)
sock.setblocking(0)

server_address = ('localhost', 10000)#192.168.56.1
print(server_address)

print('starting up on %s port %s' % server_address)
sock.bind(server_address)

# Listen for incoming connections
sock.listen(1)

while True:
    try:
        # Wait for a connection
        print >>sys.stderr, 'waiting for a connection'
        connection, client_address = sock.accept()
        connection.settimeout(0.0025)
        print >>sys.stderr, 'connection from', client_address
        break;
    except socket.timeout:
        pass
    except socket.error:
        #exit from here
        pass


# Receive the data in small chunks and retransmit it
while True:
    iRStatus = GPIO.input(IR_PIN)
    #print(iRStatus)
    if(iRStatus == 1):
        RobotSTOP()
    try:
        data = connection.recv(16)
        if data != '':
            print >>sys.stderr, 'received "%s"' % data
            if data[0] == 'w':
                RobotFWD()
            elif data[0] == 'a':
                RobotLEFT()
            elif data[0] == 's':
                RobotSTOP()
            elif data[0] == 'd':
                RobotRIGHT()
            elif data[0] == 'b':
                RobotBACK()
        time.sleep(0.01)
    except socket.timeout:
        #print('timeout')
        pass
    except socket.error:
        connection.close()
        sock.close()
        RobotDeInit()
        break
    except KeyboardInterrupt:
        # Clean up the connection
        connection.close()
        sock.close()
        RobotDeInit()
        break;

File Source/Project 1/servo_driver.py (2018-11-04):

import time
import Adafruit_PCA9685
import RPi.GPIO as GPIO
import warnings
pwm = Adafruit_PCA9685.PCA9685()

#technical min-max is 68.25 - 409.5
#to reduce noise min-max will be considered 75 - 400	
min = 75
max = 400
neutral = 205
frequency = 33.33
pwm.set_pwm_freq(frequency)

	
def SetAngle(pin,angle,wait):
	#angle is odd due to the pulse width not being evenly distributed
	#	so it will be separated into many chunks with different math for each
	#	this isn't going to work well
	#Convering from degrees to microseconds
	if angle > 90 or angle < -90:
		warnings.warn("Out of range")
	elif angle <= -45:
		angle_convert = angle * -5.6
	elif angle >= 45:
		angle_convert = angle * 22
	elif angle < 0:
		angle_convert = angle * -14
	else
		angle_convert = angle * 20
	#converting from micrseconds to milliseconds
	angle_convert = angle_convert / 1000
	#convering to number of ticks for 12 bit 
	angle_convert = angle_convert / frequency * 4096
	pwm.set_pwm(pin,0,angle_convert)
	time.sleep(wait)

def SetMicros(pin,angle,wait)	
	if angle > 2100 or angle < 500:
		warnings.warn("Out of range")
	#converting from micrseconds to milliseconds
	angle_convert = angle / 1000
	#convering to number of ticks for 12 bit 
	angle_convert = angle_convert / frequency * 4096
	pwm.set_pwm(pin,0,angle_convert)
	time.sleep(wait)
	
def TiltUp(pin,wait):
	pwm.set_pwm(pin,0,max)
	time.sleep(wait)

def TiltDown(pin,wait):
	pwm.set_pwm(pin,0,min)
	time.sleep(wait)
	
def TiltMid(pin,wait):
	pwm.set_pwm(pin,0,neutral)
	time.sleep(wait)
	
def PanRight(pin,wait):
	pwm.set_pwm(pin,0,max)
	time.sleep(wait)
	
def PanLeft(pin,wait):
	pwm.set_pwm(pin,0,min)
	time.sleep(wait)
	
def PanMid(pin,wait):
	pwm.set_pwm(pin,0,neutral)
	time.sleep(wait)

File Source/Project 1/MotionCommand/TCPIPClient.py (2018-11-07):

import socket
import sys

# Create a TCP/IP socket
sock = socket.socket(socket.AF_INET, socket.SOCK_STREAM)
sock.setsockopt(socket.SOL_SOCKET, socket.SO_REUSEADDR, 1)

# Connect the socket to the port where the server is listening
server_address = ('localhost', 10000)
print >>sys.stderr, 'connecting to %s port %s' % server_address
sock.connect(server_address)

while True:
    try:
        command = raw_input("Enter Command\n")
        print >>sys.stderr, 'sending "%s"' % command
        sock.sendall(command)
    except KeyboardInterrupt:
        break

print >>sys.stderr, 'closing socket'
sock.close()

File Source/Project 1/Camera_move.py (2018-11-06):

# import the necessary packages
from picamera.array import PiRGBArray
from picamera import PiCamera
import time
import cv2
import numpy as np
import motion as motor

# initialize the camera and grab a reference to the raw camera capture
camera = PiCamera()
camera.resolution = (640, 480)
camera.framerate = 32
rawCapture = PiRGBArray(camera, size=(640, 480))
 
# allow the camera to warmup
time.sleep(0.1)
 
faceCascade = cv2.CascadeClassifier('haarcascade_frontalface_default.xml')

faceNeighborsMax = 2
neighborStep = 1

motor.RobotInit()
 
# capture frames from the camera
for frame in camera.capture_continuous(rawCapture, format="bgr", use_video_port=True):
    # grab the raw NumPy array representing the image, then initialize the timestamp
    # and occupied/unoccupied text
    image = frame.array
    frame_h = image.shape[0] # frame_w = 640
    frame_w = image.shape[1] # frame_h = 480
    frameGray = cv2.cvtColor(image, cv2.COLOR_BGR2GRAY)
    # Perform multi scale detection of faces
    for neigh in range(1, faceNeighborsMax, neighborStep):
        #function whic detects an object
        #returns rectangles
        faces = faceCascade.detectMultiScale(frameGray, 1.2, neigh)
        frameClone = np.copy(image)
    
        # Display the image
        #for each rectangle detected
        for (x, y, w, h) in faces:
            #draw rectangle with red colour in clone image
            cv2.rectangle(frameClone, (x, y), (x + w, y + h), (255, 0, 0), 2)
            ####################################################
            # Draw a diagonal blue line with thickness of 5 px
            cv2.line(frameClone,(220, 0),(220, frame_h),(0,255,0),5) #green line
            cv2.line(frameClone,(320, 0),(320, frame_h),(0,0,255),5) #red line
            cv2.line(frameClone,(420, 0),(420, frame_h),(255,0,0),5) #blue line
                #print(' y + w/2 = %f'%(y+(w/2)))
                #print('w = %f'%w)
	        #print('h = %f'%h)
            if (220 <= (x + (w/2)) <= 420):
                print('stop')
                motor.RobotSTOP()
            elif ((x + (w/2)) < 220):
                print('turn left')
                motor.RobotLEFT()
            elif((x + (w/2)) > 420):
                print('turn right')
                motor.RobotRIGHT()
			
			
	#################################################
	# show the frame
    cv2.imshow("Frame", frameClone)
    key = cv2.waitKey(1) & 0xFF

    # clear the stream in preparation for the next frame
    rawCapture.truncate(0)
    # if the `q` key was pressed, break from the loop
    if key == ord("q"):
        motor.RobotDeInit()
        break

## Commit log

2018-10-29 Add files via upload
    To be printed final version of case
    [Vikingbot v4.f3d]
2018-11-02 Cleaning Up
    [Vikingbot v10.f3d, Vikingbot v12.f3d, Vikingbot v4.f3d]
2018-11-06 Added drive code for moving the bot and camera move to recognize face and move bot appropriatly
2018-11-07 1)Ball detection and tracking is happening at the same time 2)have made movement of servo smooth in case of smile detection 3)Have separated motion component with command component 4)IR also has been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
